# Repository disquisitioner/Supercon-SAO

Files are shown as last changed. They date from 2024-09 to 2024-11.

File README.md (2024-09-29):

# Supercon SAO Projects

Each year the Hackaday Supercon conference designs a unique badge that attendees can wear but also program.  While every year's badge is very different, they all incorporate an
add-on interface (called the ["Supercon Add-On"](https://hackaday.io/project/175182-simple-add-ons-sao) or "SAO") that exposes power and digital communications in a standardized configuration.

I'm attending Supercon for the first time in 2024 and am keen to try my hand at badge programming and SAO development. This repo serves as a collection point for software and hardware designs in support of my SAO voyage of discovery.  Everything is organized by year, as the badge, badge programming environment, and documentation changes every year.

Part of the challenge in developing an SAO add-on is that details of the badge are not released until about four weeks before the conference.  It pays, therefore, to be as prepared as possible but also stay flexible so you can react and probably re-design once actual badge specifications are known.

My newbie attempt for 2024 is to build an add-on that monitors air quality around the  badge wearer and uses a simple "stoplight" with red, yellow and green LEDs to translate current CO2 levels into subjective "good" (green), "warning" (yellow) and "alert!" (red) values.  We'll see how that goes...

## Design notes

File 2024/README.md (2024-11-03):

# Supercon 2024 Badge Add-On Project

My 2024 Supercon badge add-on is a real-time CO2 monitor with simple "stoplight" display of overall air quality using red, yellow, and green LEDs.  CO2 as a component of overall air quality isn't much talked about and health-specific requirements seem more advisory than proscriptive, but there's movement to do more in both monitoring and reducing CO2 especially in indoor settings.

This is my first Supercon and my first attempt at crafting a Supercon badge add-on, but it builds on [considerable work](https://github.com/ericklein/rco2) I've been doing with [@ericklein](https://github.com/ericklein/) exploring ways to easily measure and report [air quality](https://github.com/ericklein/air_quality) based on a wide variety of sensor inputs.

The CO2 monitor add-on we've built is based on:
* The Sensirion SCD40 true CO2 sensor, in particular the [Adafruit packaged version](https://www.adafruit.com/product/5187), which is small, accurate, supports I2C via either Qwiic connectors or dedicated wiring, provides additional on-board components for ease of use, and has mounting holes that allow it to be piggy-backed on a larger overall board or enclosure.
* Red, yellow and green rectangular LEDs with a thin outer case and diffuser, allowing them to be grouped into a single status bar, specifically [these](https://www.lumex.com/led-thru-hole-rect-1.html).
* Simple digital logic that translates the SAO connector's two GPIO digital inputs into control for the three LEDs. For me this is a delightful throwback to my college Electrical Engineering days almost exactly fifty years ago.  I know I could do this in other ways, e.g. with a smart RGB LED, but wanted to re-experience low-level digital design.
* Programming in Python with a a guess that we'd have an RP2040 main processor on the badge itself. Design and development of the add-on started in late September, about a month before Supercon but more significantly several weeks before we had any idea what the conference badge would be like or be extensible through add-ons.

I used [KiCad](https://kicad.org) to design a printed circuit board (PCB) that could  directly mount the LEDs, digital logic circuit, and SAO badge connector and also support the SCD40 breakout board both via mounting holes and connection points for the I2C interface. I knew I'd need to build and test the add-on without actually having the badge in hand. That led to the design of a simple SAO breakout board PCB that could handle either a female SAO connector (to simulate the badge itself) or a male SAO connector (to simulate being an add-on).  KiCad projects for both are here as well.

I used one of my on-hand Adafruit Feather RP2040 boards as a stand-in for the badge. That made it possible to breadboard the CO2 add-on's LED logic and connect the SCD40 via Qwiic cables, increasing my confidence in attempting a PCB design.  Development of software for that prototype was begun in CircuitPython, which Adafruit supports for both the SCD40 and Feather RP2040, knowing I should be able to migrate to MicroPython if that's indeed what would be announced for the badge (as turned out to be the case).

## The CO2 Add-On (SAO)
Here's the fully-assembled CO2 SAO as we wore it during Supercon, showing both the "stoplight" red/yellow/green LEDs on the board underneath and the Adafruit SCD40x breakout board mounted atop.
CO2 SAO Prototype

## Working Prototype
This is the first working instance of the CO2 SAO printed circuit board, in this case just with the circuitry to drive the "stoplight" of red, yellow and green LEDs.  You can see the SCD40 CO2 sensor on its separate brekaout board, connected to the Pico W via a Qwiic connector.
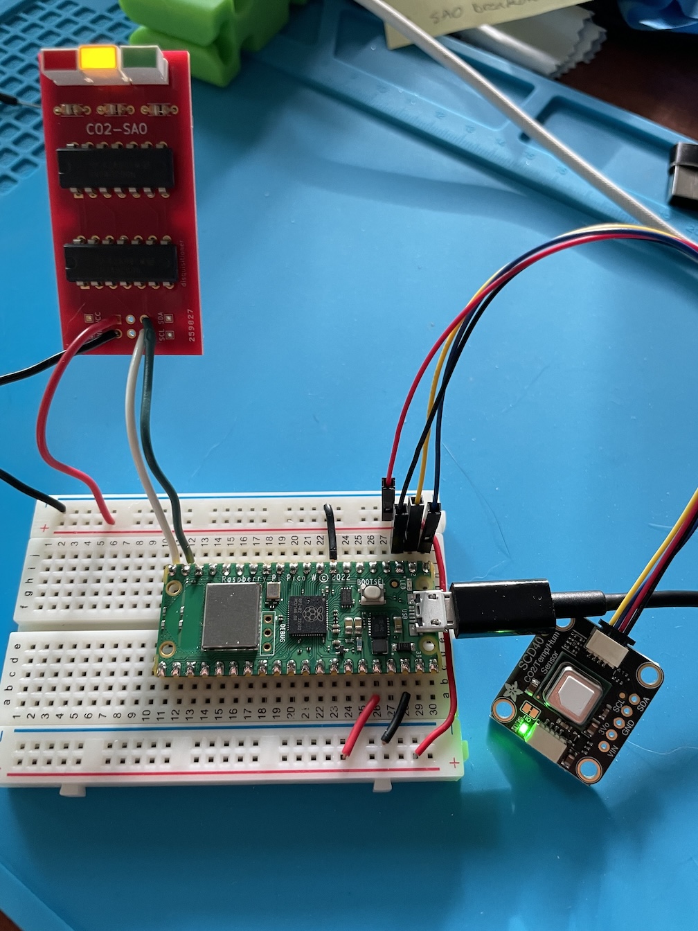
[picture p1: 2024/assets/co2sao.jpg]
CO2 SAO Prototype


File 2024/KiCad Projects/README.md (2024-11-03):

# Printed Circuit Board Designs

Part of the fun and challenge of building a Supercon badge add-on is designing a printed circuit board (PCB) to use in assembling the add-on.  I've only ever designed and built one  PCB and that was a decade ago as part of taking a class on PCB design.

Happily tools for PCB design have gotten better and freely available as open source.  Among the SAO add-on community there was lots of love for [KiCad](https://www.kicad.org/), so I gave it a try.  The getitng started documentation is very helpful, taking you through the process of designing a schematic for the PCB, laying out the board itself, using tools to check the designs, and previewing everything before submitting it for manufacture. 

Even so, PCB design is a iterative process with lots of learn by doing, which means sending designs out for fabrication and discovering what you didn't quite get right when the boards come back.  Happily getting boards produced is quick and not particularly expensive!

The KiCad files are available here. 

## Schematic
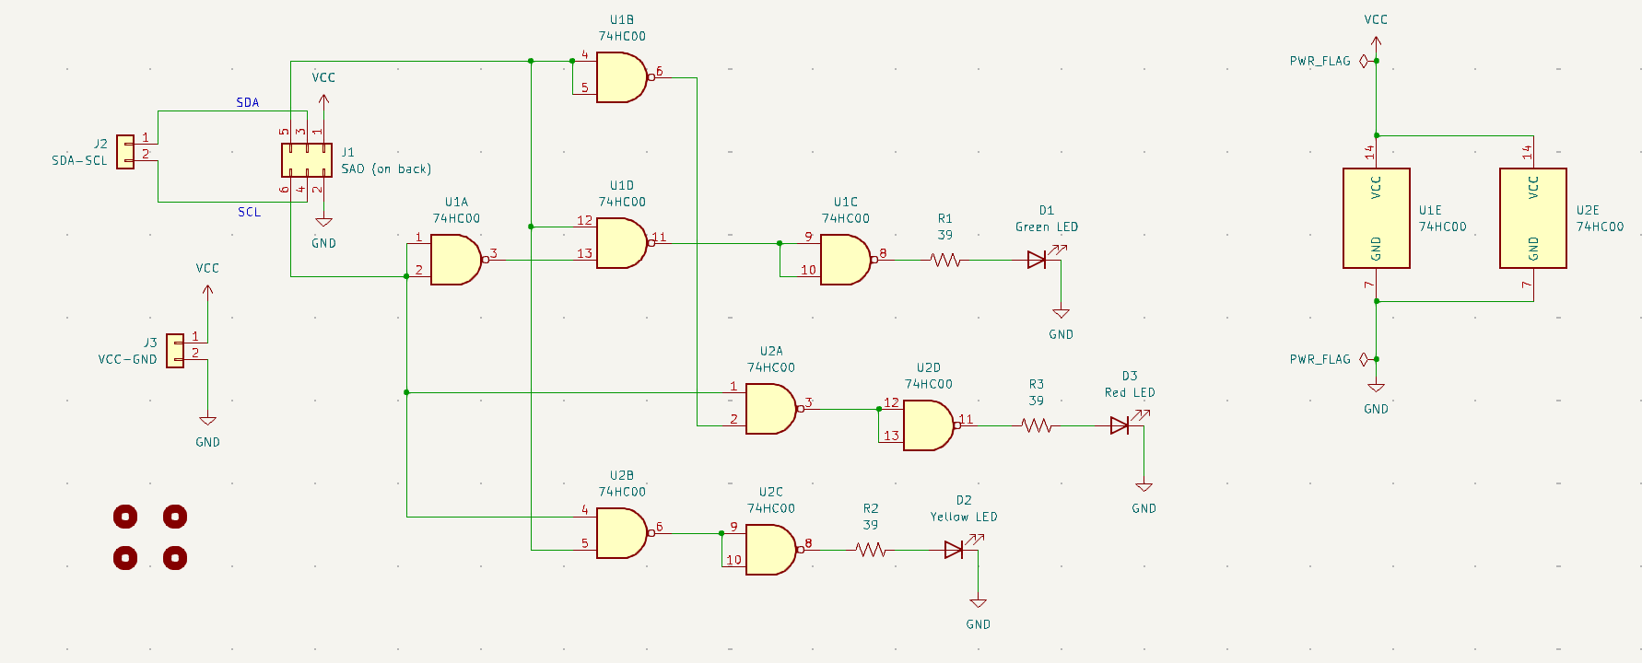
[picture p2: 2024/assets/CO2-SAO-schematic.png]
Add-on schematic

Using the two GPIO digital lines in the SAO add-on interface to control the three LEDs in the "stoplight" requires some simple digital logic to translate the four possible values of those two lines taken together (00, 01, 10, and 11) into separate single lines that drive the LEDs. That's easily done through a combination of Boolean "and" and "not" gates, but for a variety of reasons it's more commonly the case that "nand" gates (for "not-and") are used.  It would take three "and" and three "not" gates (inverters) to do the logic translation, but if done with "nand" gates you need eight overall.  Happily the 7400 digital logic IC incorporates four nand gates into a single 14-pin package, so two of those ICs get the job done.

If you're not familar with digital logic see if you can determine from the schematic how the "nand" gates make it work.

## PCB Layout
The PCB is laid out with an eye towards how the finished add-on should look.  The three LEDs should be at the top of the add-on so they're easy to see.  They each need to be connected to the output of the digital logic circuit (nand gates) that drives them in translating the values of the two GPIO inputs from the SAO add-on connector, though each LED needs a resistor to set the proper drive current for consistent overall brightness.  There are connection points that allow the CO2 sensor to be connected to the four I2C lines from the SAO add-on connector, and four mounting holes spaced to line up with the mounting holes in the Adafruit SCD40 sensor add-on board so it can be secured atop the add-on board itself.

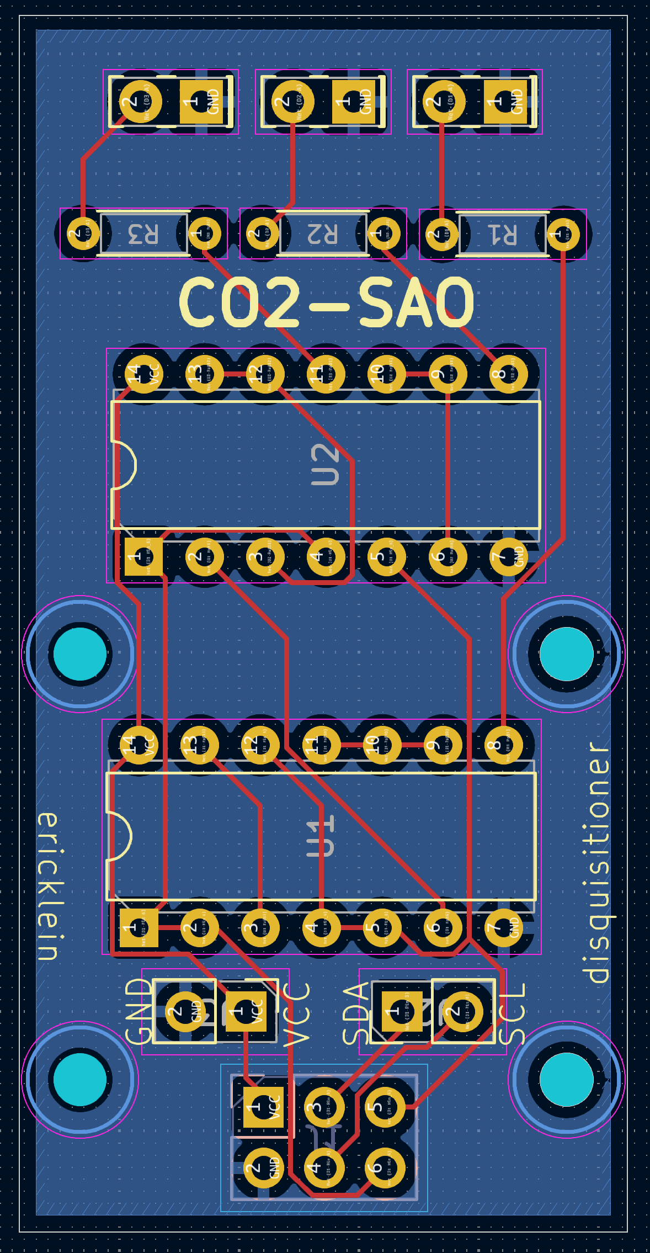
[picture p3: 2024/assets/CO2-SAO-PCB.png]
Add-on PCB layout


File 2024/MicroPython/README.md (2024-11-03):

# MicroPython Work

The Supercon 2024 badge is [built](https://hackaday.com/2024/10/22/the-2024-hackaday-supercon-sao-badge-reveal/) around the Raspberry Pi Pico W, which is great as that means there's both a familar platform underneath the badge and whatever specialized software the conference folks design for it and there's a generalized development platform we can use to design, build, and test badge add-ons even without having a badge.

That said, the badge environment does have some unique properties that mean software developed to run on a Pico W running the standard MicroPython environment won't necessarily run (or run properly) on the badge itself.  Having only just gotten my badge today at day 1 of Supercon 2024, I'm still figuring out what those differences are and how to manage code mindful of them.

In the meantime I've resorted to developing and managing two different versions of the code that runs our CO2 add-on -- one that runs in a vanila MicroPython environment on the Pico W and one that runs on the badge with its own pre-defined boot and main operating program (boot.py and main.py respectively).

The Pico W side of things is quite straightfowrard.  Create a main.py file and it'll get loaded when the device powers up.  Otherwise the Python interpreter loads and you can run commands over the console built in to Thonny as the Python REPL.   During development when I have lots of different Python programs I might be editing and running (e.g. to test out wifi connectivity or I2C operations) I give them all obvious names and run them from within Thonny.

On the 2024 Supercon badge there's already a boot.py program that loads when the device boots, and a main.py program that's intended to be the default badge main program.  Together they enable a couple of add-ons that came with the badge at the conference, but they also provide some utilities that reflect badge hardware.  In particular the 2024 badge was built around having and exploring multiple add-ons. Instead of prior year's single add-on port the 2024 badge offers six add-on connectors, three each on the two I2C busses provided by the Pico W.

This means your 2024 badge addons need to be aware of two I2C busses and be flexible about figuring out which GPIO pins are connected to any particular add-on.  A convenience function provided in the badge's pre-installed boot.py helps find the right I2C bus for any device address but you're on your own determining which GPIO pins are connected to any particuclar add-on.

In this repo I've setup separate subfolders for code that's intended to be used on a generic Pico W or on the Supercon badge. I often have both environments available during development (especially during Badge Hacking Day at Supercon itself) so not getting confused about which code runs where is important.

Generally speaking what's in each subfolder is the proper variant of the following: 
* `fauxbadge.py` - An attempt to simulate the badge software itself, which I'm guessing will handle boot-time initialization for the badge hardware and then transition to a simple main loop for ongoing operation across whichever add-ons are installed.  Both initialization and main loop will be extensible in some way to allow add-ons to be easiy added and arranged.  Until we know more I'm trying to keep this as simple as possible.
* `co2sao.py` - A minimalistic handler for the CO2 monitor add-on, providing an initializing routine as well an update function called from the badge main loop to retrieve air quality information from the add-on's sensor and update the on-board LED status bar accordingly.
* `measure.py` - A utility module that makes it easy to track a time series of sensor data and determine minimum and maximum observed values, average value, number of samples, etc.
* `co2_sao_test.py` - A stand-alone program to interface with my CO2 add-on hardware directly without any assumptions about how the badge will actually work.  This was my starting point for add-on development before knowing anything about this year's badge hardware, and is still useful for easy testing of the add-on.

A few things work in both environments:
* `scd4x.py` - A MicroPython port of the Adafruit SCD4x CircuitPython library, courtesy of @peter-l5 on [GitHub](https://github.com/peter-l5/MicroPython_SCD4X).

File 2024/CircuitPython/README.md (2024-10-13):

# CircuitPython Work

My earliest efforts at developing software for a Supercon 2024 badge add-on started with CircuitPython largely because the hardware I had at hand, both the Adafruit Feather RP2040 and SCD40 CO2 sensor breakout board, supported CircuitPython.  At this stage I was focused on prototyping something consistent with the general hardware environment a badge add-on would likely face, giving me as much time before the conference as possible to attempt a custom PCB design (or at least hand-wire something custom I could use with the badge).

I was sufficiently successful with that prototyping that I had time to learn my way around KiCad and produce a custom PCB design for my badge add-on.  Once the PCB order was placed I figured I could switch gears and tackle MicroPython, which was my (uneducated) guess as to the likely environment the 2024 Supercon badge would support.

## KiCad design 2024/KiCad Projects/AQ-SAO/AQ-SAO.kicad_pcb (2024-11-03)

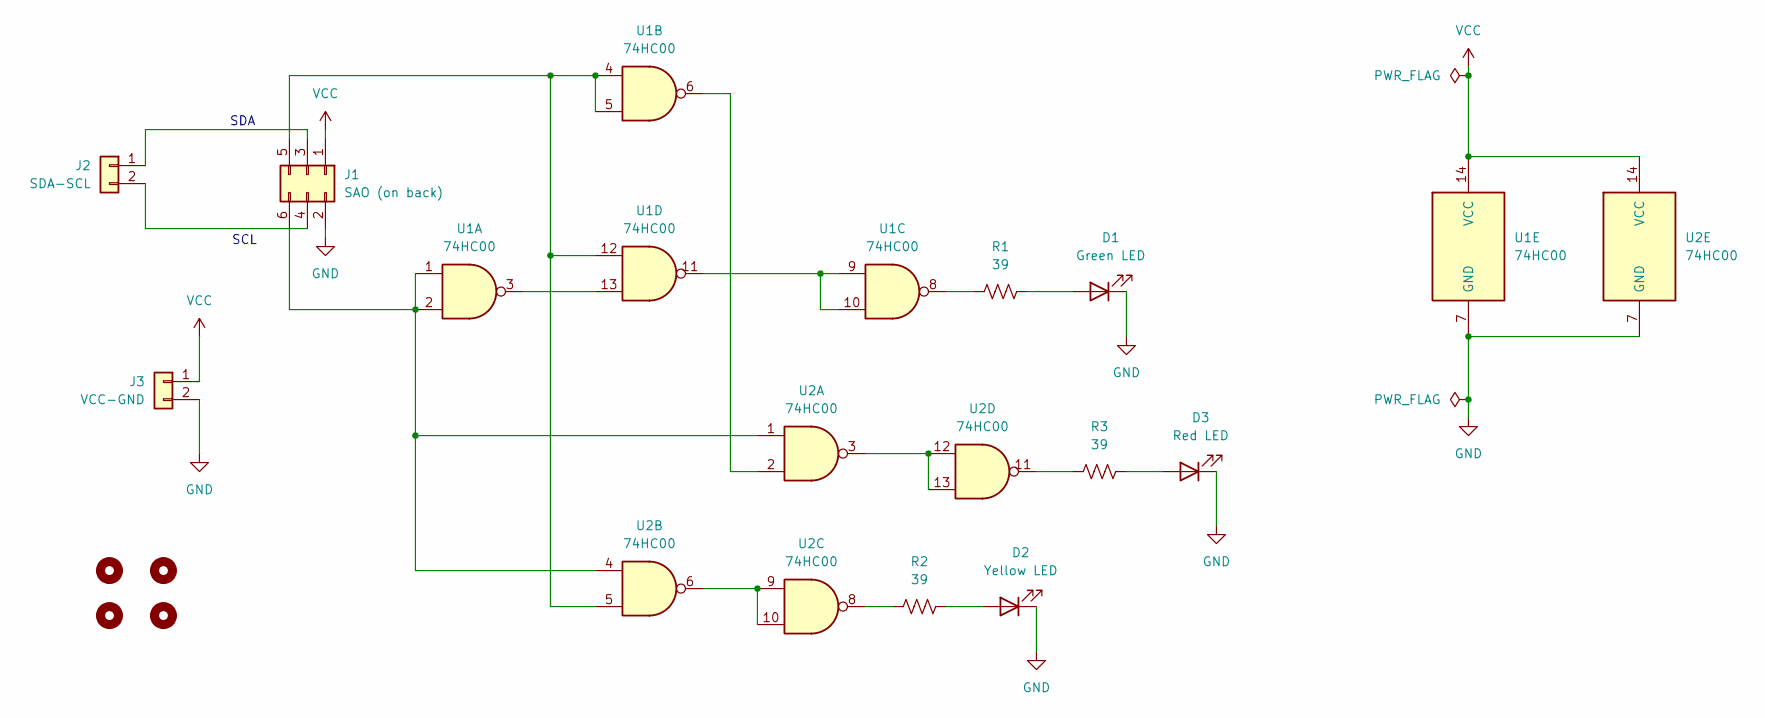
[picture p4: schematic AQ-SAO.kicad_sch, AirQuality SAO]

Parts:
D1: Green LED; LED_Rectangular_W5.0mm_H2.0mm
D2: Yellow LED; LED_Rectangular_W5.0mm_H2.0mm
D3: Red LED; LED_Rectangular_W5.0mm_H2.0mm
H1, H2, H3, H4: MountingHole; MountingHole_2.2mm_M2
J1: SAO (on back); PinHeader_2x03_P2.54mm_Vertical
J2: SDA-SCL; PinHeader_1x02_P2.54mm_Vertical
J3: VCC-GND; PinHeader_1x02_P2.54mm_Vertical
R1, R2, R3: 39; R_Axial_DIN0204_L3.6mm_D1.6mm_P5.08mm_Horizontal
U1, U2: 74HC00; DIP-14_W7.62mm

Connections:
GND: D1.1 (K), D2.1 (K), D3.1 (K), J1.2, J3.2, U1.7 (GND), U2.7 (GND)
unnamed: D1.2 (A), R1.2
unnamed: D2.2 (A), R2.2
unnamed: D3.2 (A), R3.2
unnamed: J1.3, J2.1
unnamed: J1.4, J2.2
unnamed: J1.5, U1.4, U1.5, U1.12, U2.5
unnamed: J1.6, U1.1, U1.2, U2.1, U2.4
unnamed: R1.1, U1.8
unnamed: R2.1, U2.8
unnamed: R3.1, U2.11
unnamed: U1.6, U2.2
unnamed: U1.9, U1.10, U1.11
unnamed: U1.3, U1.13
unnamed: U2.6, U2.9, U2.10
unnamed: U2.3, U2.12, U2.13
VCC: J1.1, J3.1, U1.14 (VCC), U2.14 (VCC)

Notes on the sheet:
SDA
SCL

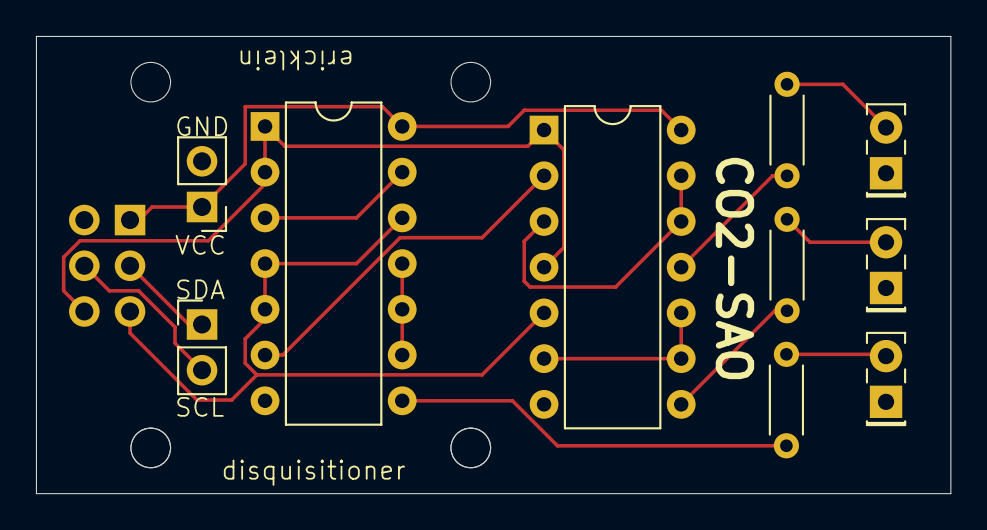
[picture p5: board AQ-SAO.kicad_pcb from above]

Board: 2 copper layers, 50.8 x 25.4 mm, 15 parts (1 on the bottom side), 17 nets.

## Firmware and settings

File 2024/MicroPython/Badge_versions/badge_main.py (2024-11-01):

from machine import I2C, Pin
import time
import scd4x
import co2sao

counter = 0

## do a quick spiral to test
if petal_bus:
    for j in range(8):
        which_leds = (1 << (j+1)) - 1 
        for i in range(1,9):
            print(which_leds)
            petal_bus.writeto_mem(PETAL_ADDRESS, i, bytes([which_leds]))
            time.sleep_ms(30)
            petal_bus.writeto_mem(PETAL_ADDRESS, i, bytes([which_leds]))

# See if we have a CO2SAO attached and if so initialize it
CO2SAO_ADDRESS     = 0x62
haveCO2SAO = False
i2cbusses = which_bus_has_device_id(CO2SAO_ADDRESS)
if len(i2cbusses) >= 1:
    print("CO2SAO detected")
    haveCO2SAO = True
    co2sao.init(i2cbusses[0])

while True:

    ## display button status on RGB
    if petal_bus:
        if not buttonA.value():
            petal_bus.writeto_mem(PETAL_ADDRESS, 2, bytes([0x80]))
        else:
            petal_bus.writeto_mem(PETAL_ADDRESS, 2, bytes([0x00]))

        if not buttonB.value():
            petal_bus.writeto_mem(PETAL_ADDRESS, 3, bytes([0x80]))
        else:
            petal_bus.writeto_mem(PETAL_ADDRESS, 3, bytes([0x00]))

        if not buttonC.value():
            petal_bus.writeto_mem(PETAL_ADDRESS, 4, bytes([0x80]))
        else:
            petal_bus.writeto_mem(PETAL_ADDRESS, 4, bytes([0x00]))

    ## see what's going on with the touch wheel
    if touchwheel_bus:
        tw = touchwheel_read(touchwheel_bus)

    ## display touchwheel on petal
    if petal_bus and touchwheel_bus:
        if tw > 0:
            tw = (128 - tw) % 256 
            petal = int(tw/32) + 1
        else: 
            petal = 999
        for i in range(1,9):
            if i == petal:
                petal_bus.writeto_mem(0, i, bytes([0x7F]))
            else:
                petal_bus.writeto_mem(0, i, bytes([0x00]))


    
    time.sleep_ms(20)
    bootLED.off()
    
    if haveCO2SAO == True:
        co2sao.update()
    
    time.sleep(1)

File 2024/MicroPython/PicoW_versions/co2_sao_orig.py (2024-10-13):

# Simple CO2 Air Quality "Stoplight"
# MicroPython Version
#
# Author: David Bryant (david@disquiry.com)
# Date: October 12, 2024
#
# This Python program reads current CO2 values from an SCD40 air quality sensor
# and translates the reading into a simple Red/Yellow/Green indication that
# can be used to drive three LEDs.
#
# It is designed to be compatible with the "SAO" connector interface built into
# Superconference badges to enable user-developed add ons.  That interface
# provides VCC, GND, I2C data (SCL & SDA) and two GPIO pins.  I2C is used to
# communicate with the SCD40 and the two GPIO pins allow four different values
# (00, 01, 10, and 11) to be processed by digital logic gates to drive the 
# red, yellow and green LEDs independently.
#
# Adjustable thresholds allow easy adjustment to the CO2 levels (in ppm) that
# define good (Green), warning (Yellow), and alert (Red).
#
# This version is developed for MicroPython, as used on Raspberry Pi devices
# and comparable ones based on the RP2040 MCU family
#
# A MicroPython port of Adafruit's SCD40 Circuit Python library is used for sensor
# communications and needs to be loaded onto the target device for
# the application to function.  That library allows setting the operating
# altitude, which should be defined properly here.  It also supports a temperature
# offset value, which is 2.0 degrees C by default but might need to be different
# depending on deployment environment.

import machine
from machine import Pin
import time
import scd4x

# Map LED control values (GPIO1 & GPIO2) to LED colors. Must agree with wiring
# on Stoplight controller board.  We're using a Grey code scheme for green ->
# yellow -> red as it seems likely green <-> yellow and yellow <-> red are the
# most likely transitions and so ideally should just be one bit different.
OFF = 0       # GPIO1 and GPIO2 both off
GREEN = 1     # GPIO1 on and GPIO2 off
YELLOW = 3    # GPIO1 and GPIO2 both on
RED = 2       # GPIO1 off and GPIO2 on

# Set sensor sample delay, in seconds.  Also used to determine whether SCD40
# can be used in low-power periodic mode or not (see SCD40 datasheet)
SAMPLE_DELAY = 40

# Specify altitude of measurement location, in meters
ALTITUDE = 400

# Define CO2 values (ppm) that constitute Red (Alarm) & Yellow (Warning) values
# US NIOSH (1987) recommendations:
# 250-350 ppm - normal outdoor ambient concentrations
# 600 ppm - minimal air quality complaints
# 600-1,000 ppm - less clearly interpreted
# 1,000 ppm - indicates inadequate ventilation; complaints such as headaches, fatigue, and eye and throat irritation will be more widespread; 1,000 ppm should be used as an upper limit for indoor levels

CO2_WARNING = 800
CO2_ALARM = 1000

# Get readings from the SCD40, which can report CO2, temperature & relative humidity
# Note that this blocks until the sensor reports it has data ready
def readco2():
    global scd4x
    
    while True:
        if scd4x.data_ready:
            tempF = (scd4x.temperature * 1.8) + 32.0
            print("%d CO2 ppm, %0.1f *F, %0.1f %%RH" % 
                (scd4x.CO2, tempF, scd4x.relative_humidity))
            # print("CO2: %d ppm" % scd4x.CO2)
            # print("Temperature: %0.1f *C" % scd4x.temperature)
            # print("Humidity: %0.1f %%" % scd4x.relative_humidity)
            # print()
            return scd4x.CO2
        else:
            time.sleep(1);
    
# Determine air quality corresponding to CO2 reading, with thresholds
# to establish green, yellow, and red status in overall PPM.  Note that
# these thresholds are somewhat arbitrary and not based on firm guidance.
def co2status(co2value):
    # AQ status is green if CO2 < WARNING level
    if co2value < CO2_WARNING:
        return GREEN
    # AQ status is yellow if WARNING <= CO2 < ALARM levels
    if co2value < CO2_ALARM:
        return YELLOW
    # AQ status is red if CO2 >= ALARM level
    return RED

# Set the stoplight LEDs based on CO2 status.  Attempts to minimize value
# flickering by (a) not changing outputs if the value hasn't changed and
# (b) using a gray code approach as described above
def setLED(newstatus):
    global _co2_status
    if newstatus == _co2_status:
        return
        
    if newstatus & 1:
        _led_bit0.value(1)
    else:
        _led_bit0.value(0)
    if newstatus & 2:
        _led_bit1.value(1)
    else:
        _led_bit1.value(0)
    _co2_status = newstatus
    return

def init():
    global scd4x,_led_bit0, _led_bit1, _co2_status
    # On-board LED, which isn't used normally but might be useful for debugging
    # led = Pin("LED", Pin.OUT)

    # The two GPIO lines for the SAO interface drive our Green/Yellow/Red LEDs.
    # status0 reflects  the low-order bit (GPIO1) and status1 is the high-order bit
    # (GPIO2) in our overall 2-bit encoding scheme.
    # 
    # Take care in mapping pin numbers silkscreened on the board to actual GPIO pin
    # IDs.  It's best to refer to the pinout for the MCU in use.  For example,
    # pins identified as "5" (D5) and "6" (D6) on the Adafruit Feather RP2040
    # itself are actually GPIO7 and GPIO8 (so must be identified as "7" and "8" \
    # respectively in calls to the MicroPython Pin() class.
    _led_bit0 = Pin(7, Pin.OUT)
    _led_bit1 = Pin(8, Pin.OUT)

    # Initialize LEDs to all off, overall CO2 status is off
    _led_bit0.value(0)
    _led_bit1.value(0)
    _co2_status = OFF

    # Connect to SCD40 and initialize
    i2c = machine.I2C(1)  # For using the Feather RP2040 built-in STEMMA QT connector
    scd4x = scd4x.SCD4X(i2c)

    # Make sure measurement is stopped so we can properly configure
    # the SCD40 and control which measurement mode to use
    scd4x.stop_periodic_measurement()
    # print("Serial number:", [hex(i) for i in scd4x.serial_number])

    # Configure SDCD40 for local use. Must do before starting measurement
    scd4x.temperature_offset = 0.0
    scd4x.altitude = ALTITUDE

    # Can use low-power measurement mode for sampling longer than 30 seconds
    if SAMPLE_DELAY > 30:
        scd4x.start_low_periodic_measurement()
    else:
        scd4x.start_periodic_measurement()
        
    print("Waiting for first measurement....")

def main():
    init()
    while True:
        # Read data from the SCD40, blocking until it has data
        co2value = readco2()
        
        # Calculate green/yellow/red CO2 air quality status from CO2 value
        newstatus = co2status(co2value)
        
        # Set status, which may result in updating stoplight LEDs
        setLED(newstatus)

        # Sleep for our sample delay period (though the SCD40 runs on its own
        # sampling clock
        time.sleep(SAMPLE_DELAY)
        
if __name__=="__main__":
    main()

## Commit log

2024-09-29 2024: CircuitPython stoplight v0
2024-10-10 KiCad projects for CO2 add-on and SAO breakout
    [AQ-SAO.kicad_pcb, AQ-SAO.kicad_sch, SAO-Breakout.kicad_pcb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]
2024-11-02 Separated Pico W and Supercon Badge variants
2024-11-03 Updating KiCad PCB files and README
    [AQ-SAO.kicad_pcb, AQ-SAO.kicad_sch]
